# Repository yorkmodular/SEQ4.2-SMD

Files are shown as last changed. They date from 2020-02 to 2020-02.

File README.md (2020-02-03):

## York Modular SEQ4.2 - 4-step CV sequencer with reset

A revamped version of my original 4-step CV sequencer.

Nothing flash here, just a regular sequencer with four steps, a reset input and an output - no muss, no fuss. Plus, it fits behind a 4HP panel.

The obligatory blinkenlights are present and correct, too. Trigger and clock require at least 3V to activate (more is better, within reason)

### Construction notes
The build is fairly straightforward, although there are a couple of things to note:

* **The counter IC should be a CD4017BM or similar **- I've had mixed success with other ICs. *74HC-series ICs should not be used* as their max supply voltage is only 5.5V or thereabouts, which limits their usefulness considerably. The ONSemi HC4017 won't work at all for reasons I've yet to fathom. The ICs I generally use are manufactured by TI and are available from the usual outlets (RS, Farnell et.al.)

* The range of the CV outputs will be determined by the voltage regulator used - assuming that red LEDs are used, there's a total voltage drop of around 2.2V between the output of the 4017 and the final output (~1.6V for the LED, 0.6V for the diode). If you want a range of 5V then I recommend a 7808/7809 regulator - if you use a 7805 (5V) regulator then the final range will be around 3V (ie. 3 octaves). Future revisions of the board may use a variable regulator.

* 100k linear taper pots are recommended for the controls - Alpha pots will give more support to the panel, but anything with a compatible footprint can be used (Alps, Bourns etc.)

### Files

* `seq4-schematic.png` - the module schematic.
* `seq4-panel.dxf` - module panel in AutoCAD DXF format.
* `seq4-panel.fpd` - module panel in Schaeffer FPD format. If you want to customise the panel then use this file and re-export it as a DXF or SVG.
* `seq4-BOM.xlsx` - Bill of Materials (BOM) file.

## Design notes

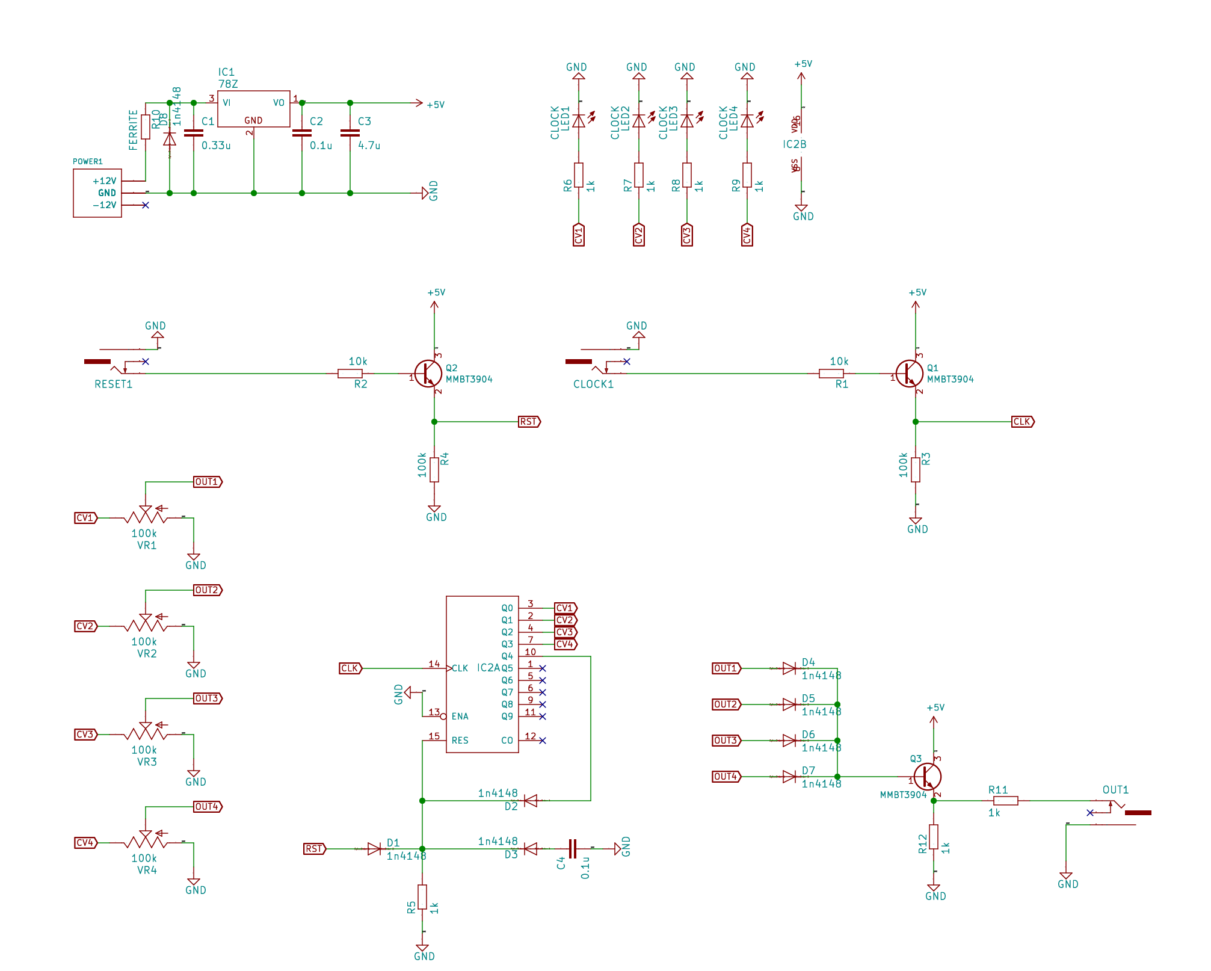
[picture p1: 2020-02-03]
seq4-schematic.png

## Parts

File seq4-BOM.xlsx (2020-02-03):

Designator | Package | Quantity | Designation | Notes
Q3,Q2,Q1 | SOT-23_Handsoldering | 3 | MMBT3904 | Any small signal NPN diode (2222 etc.) can be used
D8,D7,D6,D5,D4,D3,D2,D1 | SOD323-W | 8 | 1n4148 | Schottky diodes can be used to reduce the voltage drop to around 0.2V
IC2 | SO16 | 1 | 4017D | Use CD4017BM or similar – 74HC devices will not work.
C1 | C_0805_2012Metric_Pad1.15x1.40mm_HandSolder | 1 | 0.33u
C2,C4 | C_0805_2012Metric_Pad1.15x1.40mm_HandSolder | 2 | 0.1u
C3 | C_0805_2012Metric_Pad1.15x1.40mm_HandSolder | 1 | 4.7u
R11,R6,R7,R8,R9,R5,R12 | R_0805_2012Metric_Pad1.15x1.40mm_HandSolder | 7 | 1k
R2,R1 | R_0805_2012Metric_Pad1.15x1.40mm_HandSolder | 2 | 10k
R4,R3 | R_0805_2012Metric_Pad1.15x1.40mm_HandSolder | 2 | 100k
R10 | R_0805_2012Metric_Pad1.15x1.40mm_HandSolder | 1 | FERRITE
IC1 | TO92 | 1 | 78Z | Use 7805 for ~3 octave range, 7808 for ~5 octave range.
POWER1 | POWER_10 | 1 | POWER_SIMPLE10
VR1,VR2,VR3,VR4 | 9MM_SNAP-IN_POT | 4 | 100k | Linear taper recommended
LED1,LED2,LED3,LED4 | LED3MM | 4 | CLOCK | Red LEDs recommended
OUT1,RESET1,CLOCK1 | WQP-PJ301M-12_JACK | 3 | THONKICONNNEW

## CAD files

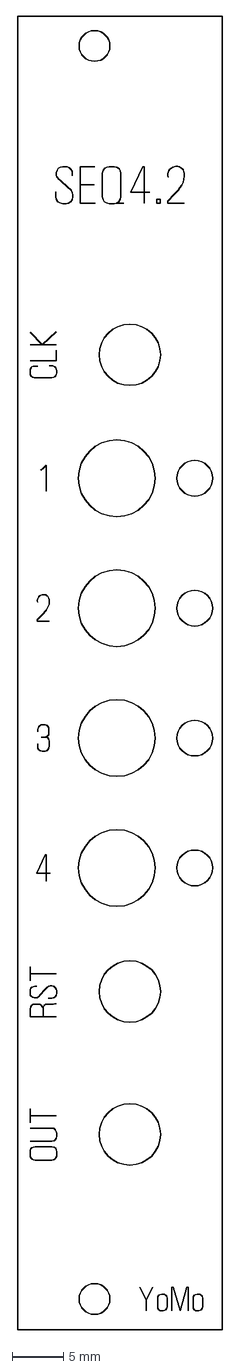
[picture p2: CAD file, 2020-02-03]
seq4-panel.dxf
20.0 x 128.4 mm
